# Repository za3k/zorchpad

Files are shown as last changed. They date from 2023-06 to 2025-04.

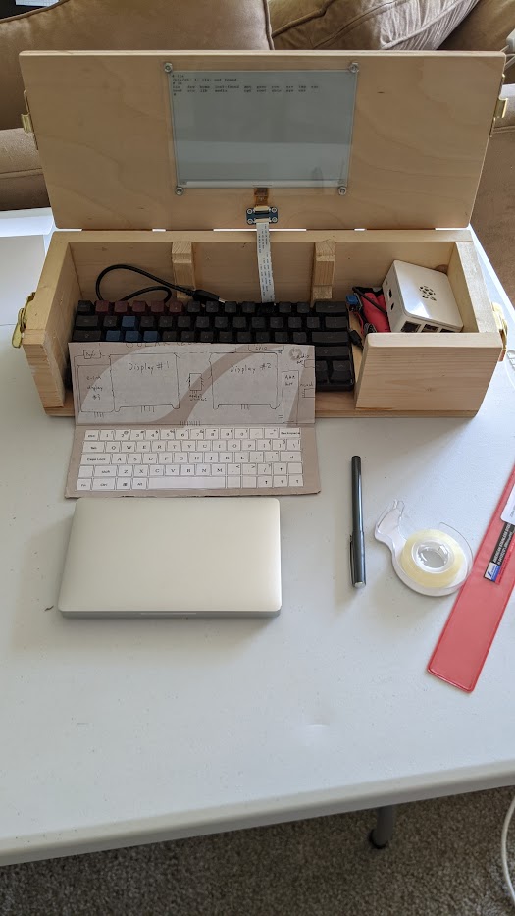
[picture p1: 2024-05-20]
photos/cardboard_zorchpad_comparison.jpg

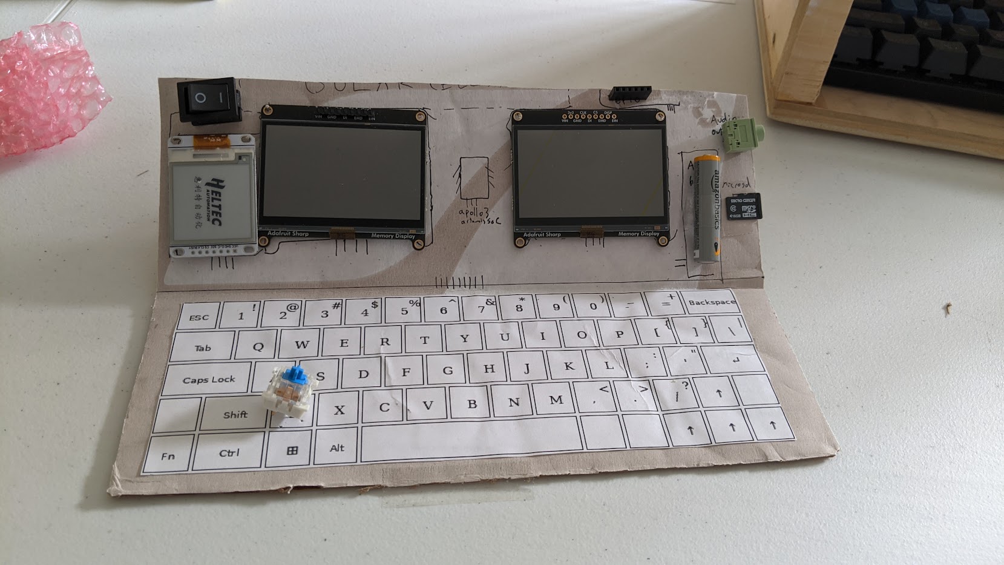
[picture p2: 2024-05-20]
photos/v0_cardboard_zorchpad.jpg

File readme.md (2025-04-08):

## (WIP) Zemu
The 'zorchpad emulator'. A basic C interface, abstracting the hardware of the zorchpad. Has a version which runs on the zorchpad and one that runs locally on PC for ease of development.

- Set/unset pixel
- Refresh screen
- Play tone
- Sleep (millis)
- Get current held key (if queue disabled)
- Get last pressed key (if queue enabled)

## Arduino Sketches

- `audio_out`: Basic beep, by rapidly toggling one pin
- `demo_screen`: A general graphics demo for the SHARP display
- `display_ram`: Output the contents of memory to the serial console and the SHARP display.
- `font`: Display text to the SHARP screen
- `keyboard_echo`: Echoes text from the keyboard to the SHARP display
- `morse_out`: Output arbitrary text to audio using morse code
- `sharp_memory_display`: Make something appear on the SHARP display

## Other
- `case_openscad`: Design of a case to hold all the parts (discontinued)
- `keyboard_layout`: Python code to generate an image of the keyboard layout.
- `yeso`/`zeso`: A low-level graphics library, used by emulator.
- `zi`: A very simple text editor based on ae.c by Anthony Howe. (unfinished)

## Parts List

From muurkha:

- one or two of the Ambiq Apollo3 devboards (probably not the
  Arduino-sized one);
- two of the 400×240 memory-in-pixel displays; and
- one or more of the Cypress S34MS01G200TFI900 gibibit Flash chips.

Purchased list:

- $21.50 Ambiq Apollo3 SoC breakout dev board. Sparkfun: [Sparkfun DEV-15444][1] (x1)
    - [Apollo3 Blue Datasheet][6] [(ambiq)][7]
        - 16 mA max current draw from I/O pins
    - [Cortex M4 Datasheet][18] [Tech Manual][19]
    - [Schematic][8]
    - [Integration Guide][9]
    - [Arduino Support][10]
    - [Visual Guide to Features][19]
    - Works with Arduino IDE
    - [Arduino Setup][18]
- $9.95 Ambiq Apollo3 SoC module. Sparkfun: [Sparkfun WRL-15484][2] (x2)
    - [Apollo3 Blue Datasheet][6] [(ambiq)][7]
    - [Cortex M4 Datasheet][18] [Tech Manual][19]
    - [Integration Guide][9]
    - [Schematic][11]
    - [Pinout][12]
- $44.95 Adafruit SHARP Memory Display Breakout - 2.7" 400x240. Adafruit: [Adafruit 4694][3] (x2)
    - [Adafruit Guide][13]
    - [Datasheet][14]
    - [Arduino Library][15]
- $6.46 4 GBit Parallel NAND (45ns). Digi-key: [S34MS04G204TFI010][4] (x2)
    - Note: 1Gbit is more like $1 but out of stock atm.
    - [Datasheet][16]
- $21.90 Low-power radio (optional). WIO-E5 MINI DEV BRD STM32WLE5JC. Digi-key, seeed studio: [Seeed 113990939][5] (x1)
    - [Datasheet][17]

Possible additional parts:
    Microsd connector (surface-mount and through-hole available)

[1]: https://www.sparkfun.com/products/15444
[2]: https://www.sparkfun.com/products/15484
[3]: https://www.adafruit.com/product/4694
[4]: https://www.digikey.com/en/products/detail/cypress-semiconductor-corp/S34MS04G204TFI010/4457680
[5]: https://www.digikey.com/en/products/detail/seeed-technology-co-ltd/113990939/13926228

[6]: https://cdn.sparkfun.com/assets/1/5/c/6/7/Apollo3-Blue-MCU-Datasheet_v0_15_0.pdf
[6]: datasheets/Apollo3-Blue-SoC_Datasheet.pdf
[7]: https://ambiq.com/wp-content/uploads/2020/10/Apollo3-Blue-SoC-Datasheet.pdf
[8]: https://cdn.sparkfun.com/assets/4/5/a/3/e/RedBoardArtemisSchematic.pdf
[8]: datasheets/Artemis-RedBoard_Schematic.pdf
[9]: https://cdn.sparkfun.com/assets/8/7/5/3/f/Artemis_Integration_Guide.pdf
[10]: https://github.com/sparkfun/Arduino_Apollo3
[11]: https://cdn.sparkfun.com/assets/5/c/b/3/c/SparkFun_Artemis.pdf
[11]: datasheets/Artemis_Schematic.pdf
[12]: https://cdn.sparkfun.com/assets/9/a/7/1/c/ArtemisModule_Pinout.pdf
[12]: datasheets/Artemis_Pinout.pdf
[18]: https://documentation-service.arm.com/static/62053f0a0ca305732a3a5c17?token=
[18]: datasheets/Arm-Cortex-M4_Datasheet.pdf
[19]: https://documentation-service.arm.com/static/5f19da2a20b7cf4bc524d99a?token=
[19]: datasheets/Arm-Cortex-M4_Manual.pdf

[13]: https://learn.adafruit.com/adafruit-sharp-memory-display-breakout
[14]: https://cdn-learn.adafruit.com/assets/assets/000/094/215/original/LS027B7DH01_Rev_Jun_2010.pdf?1597872422
[14]: datasheets/Sharp_LCD_Datasheet.pdf
[15]: https://github.com/adafruit/Adafruit_SHARP_Memory_Display

[16]: https://media.digikey.com/pdf/Data%20Sheets/Cypress%20PDFs/S34MS01G2_2G2_4G2_RevE_6-9-17.pdf
[16]: datasheets/Flash_Datasheet.pdf

[17]: https://files.seeedstudio.com/products/317990687/res/LoRa-E5%20module%20datasheet_V1.0.pdf
[17]: datasheets/Radio_Datasheet.pdf

[18]: https://learn.sparkfun.com/tutorials/artemis-development-with-arduino/all
[19]: https://learn.sparkfun.com/tutorials/hookup-guide-for-the-sparkfun-redboard-artemis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

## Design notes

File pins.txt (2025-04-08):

    37 or 50 GPIO pins?
Available (small package)
    BTLE
    33 pins (?)
    Will require either surface-mount soldering or whisker-thin wires (quite small but not theoretically un-doable)
Available (large package)
    22 pins (?)
    Can just use standard pitch headers

Requirements:
    9 pins (9 IO) - keyboard
    0 pins - power input
    7 pins (5 out, 2 IO) - SPI
        4 devices: Screen 1, Screen 2, MicroSD, E-ink
        4x chip select, 1 clock, 1 MOSI, 1 MISO
    2? pins (2 out) - Headphones
    0 pins - Microphone (integrated)
    GPIO (???? Active research)
        3 IO?)
        (shared clock with SPI)

21 pins total (7 out-only, 14 IO, 0 in)

-------------------------------------

Voltages
    Component       Operating Voltage
    ---------       -----------------
    Screen 1+2
            power   4.8-5
            I/O     2.7-3
    E-ink* 
            power   2.3-3.6 (3.3)
            I       2.3-3.6 (3.3)
            O       power minus 0.4
    Microsd**       3.3
    Artemis/Apollo3
     Redboard in    5
     Redboard out   3.3 (nominal?)
     apollo3 in     1.755-3.63
     apollo3 out    unknown
    Headphones      (Match apollo3/artemis logic output)
    GPIO            (Match shift register)
    Keyboard        (Match shift register)
    Radio           1.8-3.6
    Shift Register  ????

*this might be incorrectly for the red-white-black display, and does not consider the board it's mounted to.
    https://resource.heltec.cn/download/e-ink/154/1.54b%26w%26r/HTEW0154Z17_V11/HTEW0154Z17_V11.pdf source
**there also a is a low-voltage (1.8V) standard from 2017, but not even all new cards support it.

(ACTIVE RESEARCH)
Serial-in, parallel out
    SN74HC595B
    2-6V
Parallel-in, serial out

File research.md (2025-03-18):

Power Usage

- Power usage will be around 0.3mA @ 3V when active (0.001 W = 0.001 J/s)
- Power usage will be around 1nA @ 3V when asleep (0.000000003 W = 0.000003 J/s)

- On 2024-08-20 I tested an e-ink power supply (Waveshare 8" display) and tried updating one character at a time, watching an oscilloscope to measure power roughly. I calculated that a refresh takes 0.0375J (4ms x 250 mA x 5V) -- affordable once per 37s. I did not test cleanly how much changing different fractions of the screen affected the power.

Continuous Power Sources

- Solar
    - 20-100 lumens per watt ??
    - ~1M lux = 1W/cm^2, ~1000 lux = 1mW/cm^2 ??
    - Outdoor, daylight
        0.138 W/cm^2
    - Outdoor, night
    - Outdoor, night (IR from earth)
        Undeveloped tech
    - Indoor, electric light
        3.5-30 uW per cm^2 [source](https://blog.powerfilmsolar.com/education/the-horizon-blog/2018/8/10/outdoor-vs-indoor-solar-the-key-differences). That's 4,000x-40,000x lower than daylight. Call it 10,000x lower.
- Amorphous silicon (calculator solar cell) - 7% efficient. 0.24W per 5cm square in daylight. 0.024 mW indoors.
- Monocrystaline silicon (standard solar cell) - 15% efficient, 0.5W per 5cm square in daylight. 0.05 mW indoors.
- Keyboard typing power
- Peltier heat differential
- Tritium battery (40 W/kg, half life 12.3 years) or other betavoltaics - Maybe 1μW
- Inductive powerline charging

Batteries

- [Lithium coin cell battery life](https://www.embedded.com/how-much-energy-can-you-really-get-from-a-coin-cell/) by Jack Ganssle, 2014. Mentions internal resistance of batteries go up as they discharge.
    225 mAh = 0.225Ah = (0.225A) * (3600s) * (2-3V) = 1620-2430 J
    Shelf life? Perhaps 10 years?

    **Runtime: 18 days active, 17,000 years inactive**
- 18650 standard lithium ion (lipo) battery.

    [source](https://nathanruffing.com/wtw22/)
    ```
    1 18659 Li-ion cell = 43,074 J
    1 Calorie = 4,180 J
    1 smartphone battery charge: 41,750 J
    1 BTU = 1,060 J
    1 kBTU = 1,000,060 J
    1 watt-hour = 3,600 J
    1 kilowatt-hour = 3,600,000 J
    2,000 Calories = 8,400,000 J
    1 gallon of gas: 120,000,000 J
    ```

    18650 battery: 43,074 J 

    **Runtime: 1.3 years active, 455,000 years inactive**
- Capacitor energy
    Charge (coulombs) is capacitance (farads=coulomb/volt) times volts: Q = F V
    Energy is joules = 0.5 Q V = 0.5 F V V
        where V is voltage and F is capacitance in farads
    The biggest capacitor I have is
        1000uF, rated to 16V. This stores 0.256 J

    Runtime: 4 minutes active, 23 hours deep sleep mode

    Online, I can get a 2.7V, 1F capacitor. This stores 7.29J.
    Runtime: 20 minutes active, 15 days deep sleep mode

    Online, I can get a 25V, 1F capacitor. This stores 625J.
    Cost ≤ $0.50
    **Runtime: 7 day active, 19 year deep sleep mode**

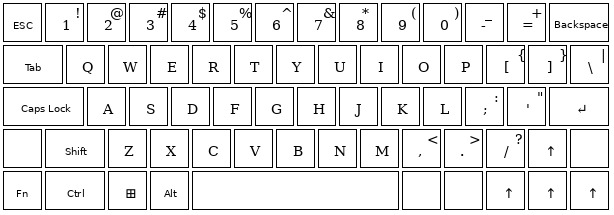
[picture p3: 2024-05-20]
photos/v0_keyboard.jpg

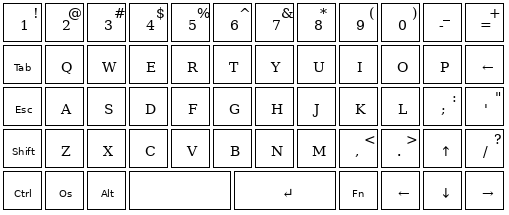
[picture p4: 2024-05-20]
photos/keyboard57.png

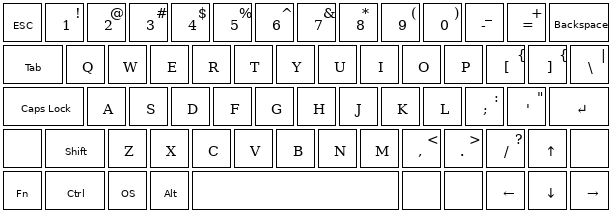
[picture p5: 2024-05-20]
photos/keyboard65.png

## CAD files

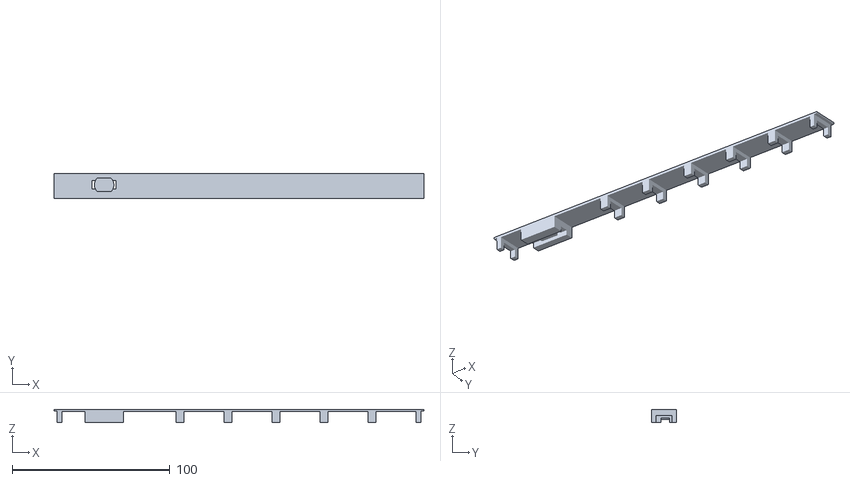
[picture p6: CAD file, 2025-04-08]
src/case_adam/Panel.stl
234.3 x 16.1 x 8.50

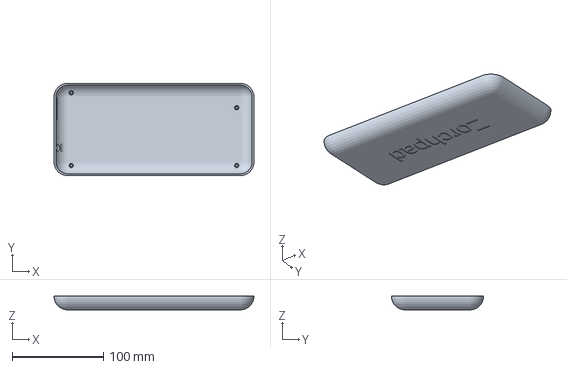
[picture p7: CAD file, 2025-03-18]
src/case_openscad/top_shell.3mf
219.7 x 101.2 x 14.9 mm

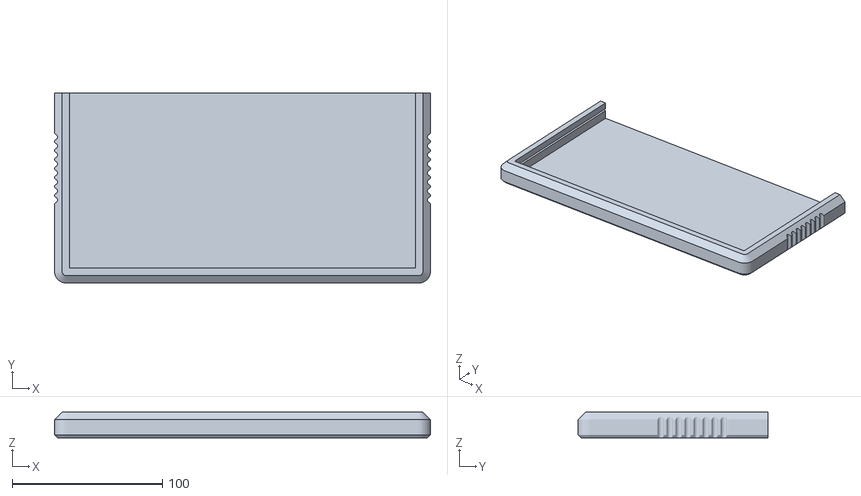
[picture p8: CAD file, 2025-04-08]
src/case_adam/Bottom Shell.stl
250.6 x 126.9 x 17.0

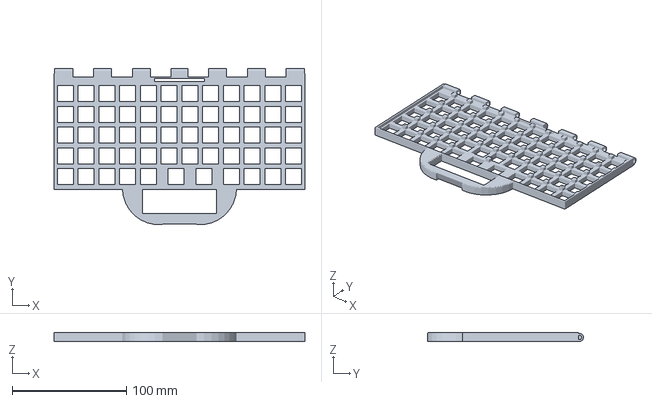
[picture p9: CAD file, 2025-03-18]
src/case_openscad/keyboard_plate.3mf
219.7 x 136.7 x 7.80 mm

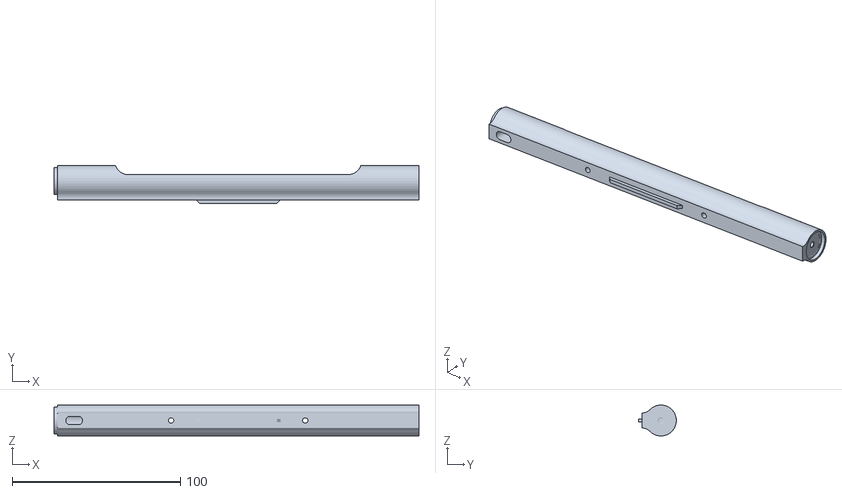
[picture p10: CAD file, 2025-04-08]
src/case_adam/Hinge.stl
216.8 x 22.4 x 18.4

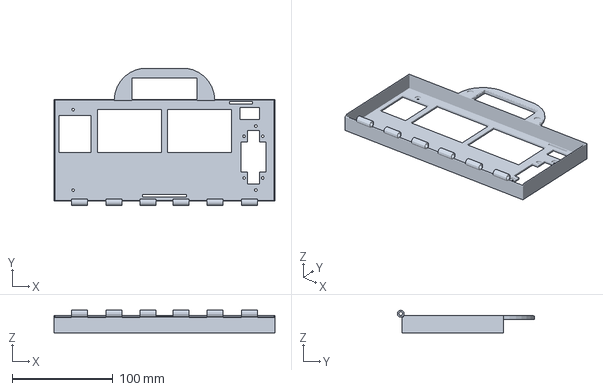
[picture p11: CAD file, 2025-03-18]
src/case_openscad/top_plate.3mf
219.7 x 136.7 x 22.5 mm

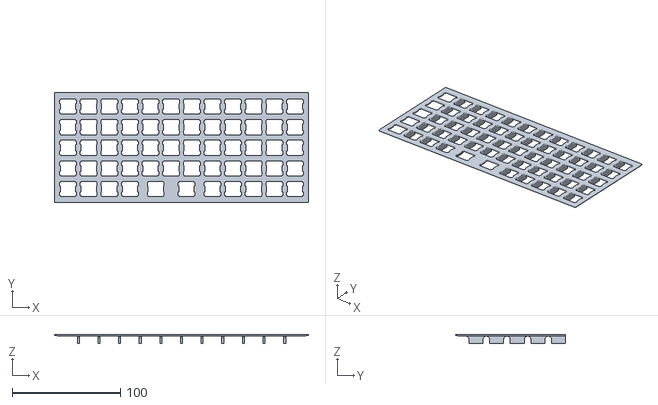
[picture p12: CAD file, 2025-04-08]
src/case_adam/Keyboard Plate v1.stl
234.6 x 101.8 x 8.25

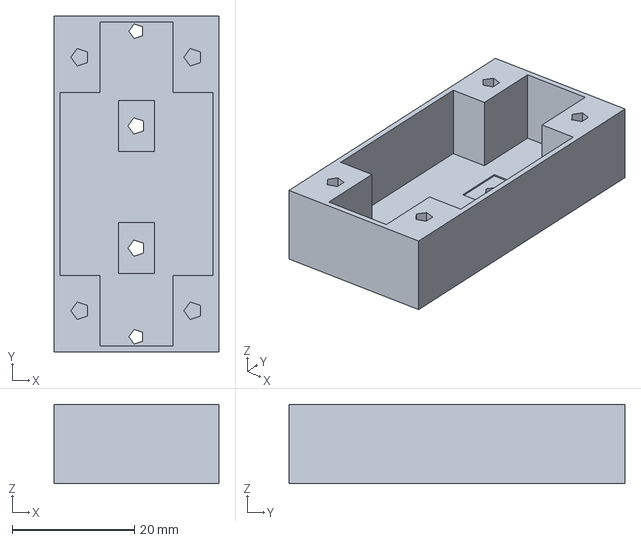
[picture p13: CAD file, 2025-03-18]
src/case_openscad/battery_box.3mf
27.0 x 55.0 x 13.0 mm

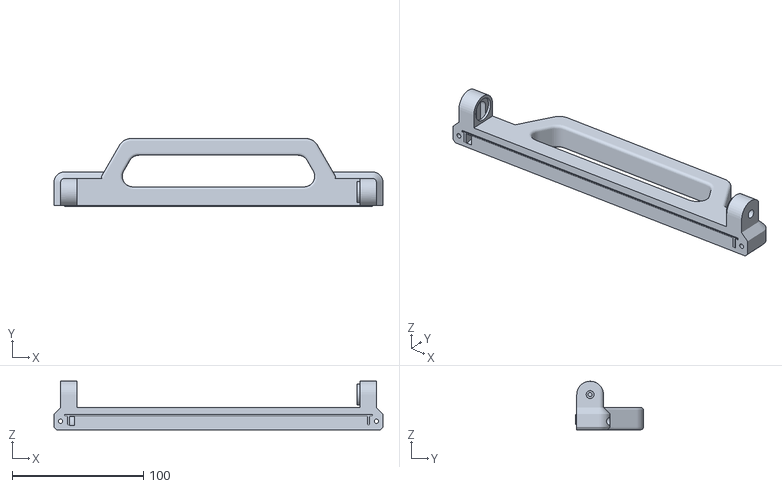
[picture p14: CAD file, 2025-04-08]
src/case_adam/Bottom Shell Rear.stl
250.6 x 51.7 x 37.0

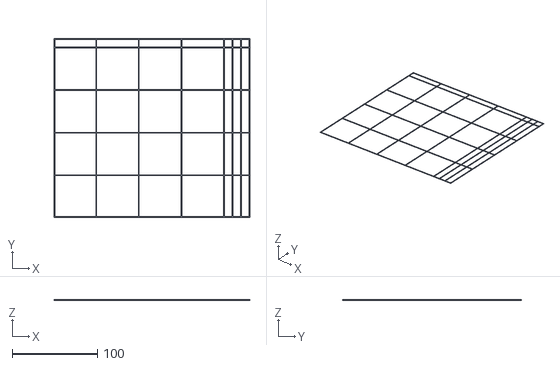
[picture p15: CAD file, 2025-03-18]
src/case_openscad/test_grid.stl
230.0 x 210.0 x 0.2

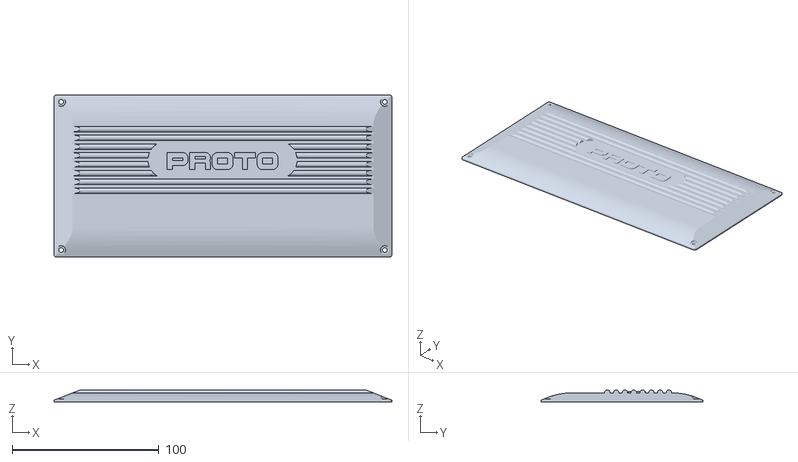
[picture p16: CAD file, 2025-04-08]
src/case_adam/Lid.stl
230.3 x 110.6 x 8.25

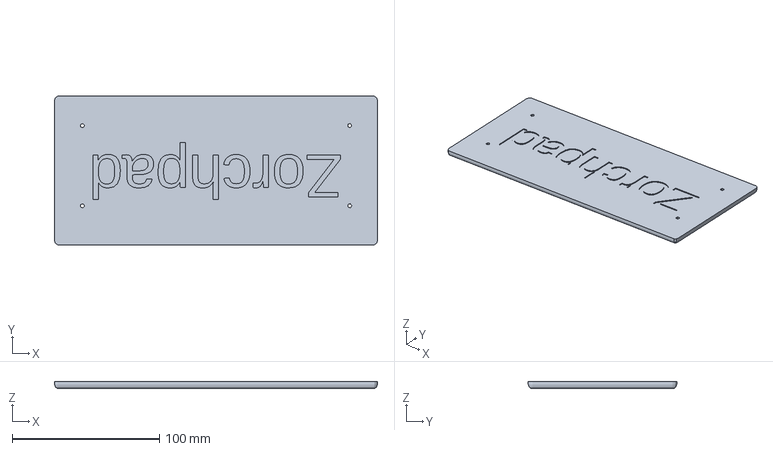
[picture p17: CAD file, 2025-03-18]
src/case_openscad/bottom_shell.3mf
219.7 x 101.1 x 4.85 mm

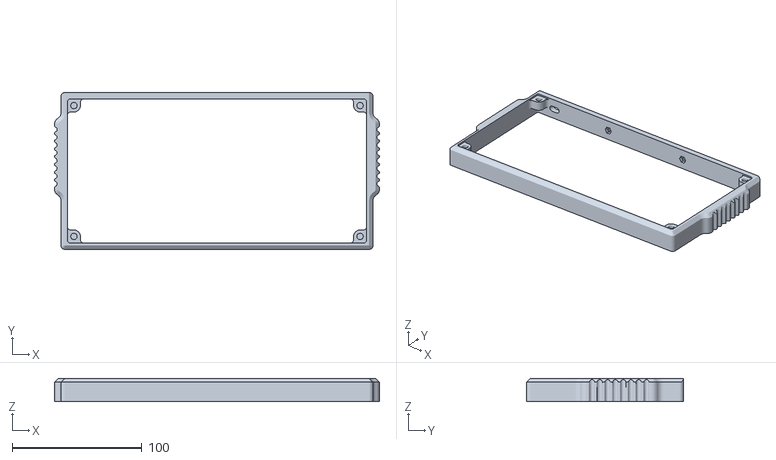
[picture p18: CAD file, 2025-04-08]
src/case_adam/Top Shell.stl
250.6 x 120.9 x 18.0

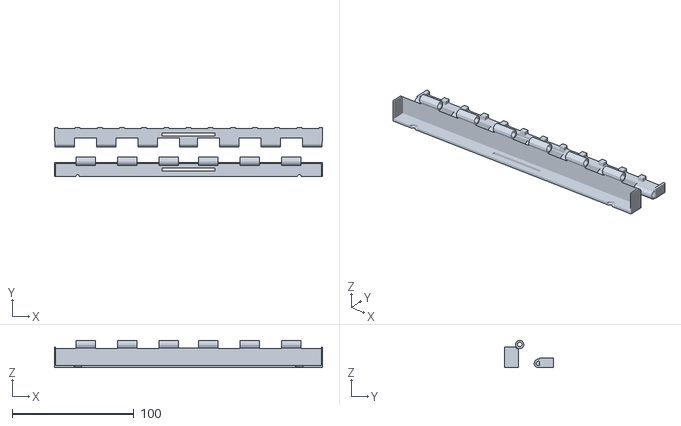
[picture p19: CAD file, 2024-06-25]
src/case_openscad/hinge.stl
219.7 x 40.0 x 22.5

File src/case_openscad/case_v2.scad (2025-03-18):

// Designed by Zachary Vance for the "Zorchpad"
//
// TO EXPORT STL FILES, run the following in a shell:
//   for part in top_shell bottom_shell keyboard_plate top_plate battery_box; do openscad -D part=\"$part\" -o $part.stl "case.scad" done
// (or if you have no idea what that means, change this variable:
part = "";
// To each of the 5 values listed above and export STL manually after each re-render.
cool_render = true;

side_thickness = 0.8;
keyboard_thickness = 4.8;

// Add a little extra room on the keyboard edges (l, r, t, b)
keyboard_edges = [side_thickness, side_thickness, 5, 2];
// There's a rim around the bottom of the keyboard to hold it up. How wide is it?
keyboard_rim = 1.5;
// How tall is the rim around the keyboard and the spacers
spacer_height = 3;

edge_left = keyboard_edges[0];
edge_right = keyboard_edges[1];
edge_top_suggestion = keyboard_edges[2]; // at y>0
edge_bottom = keyboard_edges[3];

// Keyboard grid size (h, v)
grid = [12, 5];
rows = grid[1]; cols = grid[0];
// Horizontal and vertical key spacing
//18.25 vs 18.3
key_size = [18.05, 18.05];
key_gap_size = [0.125, 0.125];
key_pitch = [key_size[0]+key_gap_size[0],key_size[1]+key_gap_size[1]];
key_spacing_h = key_pitch[0];
key_spacing_v = key_pitch[1];
// Hole size (h, v)
hole_size = [14, 14];
hole_size_h = hole_size[0];
hole_size_v = hole_size[1];

// How much do the complete keys protrude above the keyboard?
keycap_height = 15;

spacer_side_h = key_spacing_h - hole_size_h;
spacer_side_v = key_spacing_v - hole_size_v;

// M2 screw sizes
screw_diameter = 2;
screw_countersink_diameter = 3.5+2;
screw_countersink_depth = 1.5;
screw_diameter_safety = 1;
screw_insert_diameter = 4;

// add room for 17-pin header (h, v)
pins_header = [43.5, 2.5];
pins_width = pins_header[0];
pins_height = pins_header[1];
edge_top = max(edge_top_suggestion, pins_height + 6);


// Clamshell (bottom keyboard half)
clamshell_depth_b = 5;
clamshell_thickness = 2;

// Clamshell (top half)
clamshell_depth_t = 15;
plate_thickness = 2;


magnet_diameter = 6;
magnet_thickness = 1.5;

logo_depth = 0.7;

// Handle
handle_size = [100, 32];
handle_length = handle_size[0];
handle_width = handle_size[1];
handle_groove_size = [65, 22];
handle_groove_length = handle_groove_size[0];
handle_groove_width = handle_groove_size[1];
handle_rounding = 1;

// Hinge
hinge_w=0;
hinge_h=0;
hinge_d=0;
hinge_hole_dia=0;
hinge_hole_offset1=0;
hinge_hole_offset2=0;

logo_back = true;
logo_ui = true;
logo_hidden = true;

top_plate_rounded = true;

// Sides (attached to top plate)

nothing = 0.001;
big = 1000;

// x = width = col #
// y = thickness = row # 
// z = height

module rounded_linear_extrude(depth, radius, slices=50) {
    // Slice from 0...radius,             use 'offset'
    // Slice from radius..(depth-radius), just flat
    // Slice from (depth-radius)..radius, use 'offset'
    slice_thickness = depth/slices;
    union() {
        for (dz = [0:slice_thickness:depth]) {
            translate([0,0,dz])
            linear_extrude(slice_thickness+nothing)
            rounded_linear_extrude_crossection(depth, radius, dz) children();
        }
    }
}
module rounded_linear_extrude_crossection(depth, radius, dz) {
    d_end = (dz >= depth-radius) ? depth-dz-radius : (
        (dz <= radius) ? dz-radius : 0
    );
    
    // Rounded chamfer, not triangular
    inset = sqrt(radius*radius-d_end*d_end)-radius;
    
    offset(inset)
    children();
}

module flat_hole(x, y, width, height) {
    translate([x, y]) {
        square([width, height]);
    }
}

connections = [
    [1,[0]],
    [2.25, [0,24]],
    [2.75, [10,34]],
];
module key(x, y, width=1) {
    if (width <=1) key_hole(x, y, width);
    else {
        for (option = connections) {
            if (option[0] == width) {
                for (j = option[1]) {
                    translate([j,0])
                    key_hole(x, y,1);
                }
            }
        }
    }
}

module key_hole(x, y, width) {
    side_h = (key_spacing_h - hole_size_h)/2;
    side_v = (key_spacing_v - hole_size_v)/2;
    w = key_spacing_h*width - side_h*2;
    flat_hole(
        edge_left + x*key_spacing_h + side_h,
        edge_top + y*key_spacing_v + side_v,
        w, hole_size_v
    );
}

module support(x, y) {
    translate([x, y, -spacer_height/2])
    cube([spacer_side_h, spacer_side_v, spacer_height], center=true);
}

module key_support(x, y, width) {
    corner_x = edge_left + x*key_spacing_h;
    corner_y = edge_top + y*key_spacing_v;
    support(
       corner_x, corner_y
    );
}

board_w = edge_left + key_spacing_h * cols + edge_right;// + 2*key_gap_size[0];
board_h = edge_top  + key_spacing_v * rows + edge_bottom;// + 2*key_gap_size[1];

module pin_hole() {
    min_gap_to_keys = (key_spacing_v-hole_size_v);
    
    translate([board_w/2-pins_width/2, edge_top-min_gap_to_keys]) {
        square([pins_width, pins_height]);
    }
}

keys = [
    // Row, Column
    [0, 0, 1], [0, 1, 1], [0, 2, 1], [0, 3, 1], [0, 4, 1], [0, 5, 1], [0, 6, 1], [0, 7, 1], [0, 8, 1], [0, 9, 1], [0, 10, 1], [0, 11, 1],
    [1, 0, 1], [1, 1, 1], [1, 2, 1], [1, 3, 1], [1, 4, 1], [1, 5, 1], [1, 6, 1], [1, 7, 1], [1, 8, 1], [1, 9, 1], [1, 10, 1], [1, 11, 1],
    [2, 0, 1], [2, 1, 1], [2, 2, 1], [2, 3, 1], [2, 4, 1], [2, 5, 1], [2, 6, 1], [2, 7, 1], [2, 8, 1], [2, 9, 1], [2, 10, 1], [2, 11, 1],
    [3, 0, 1], [3, 1, 1], [3, 2, 1], [3, 3, 1], [3, 4, 1], [3, 5, 1], [3, 6, 1], [3, 7, 1], [3, 8, 1], [3, 9, 1], [3, 10, 1], [3, 11, 1],
    [4, 0, 1], [4, 1, 1], [4, 2, 1],
    [4, 3, 2.25], [4, 5.68, 2.25], // Spacebar, enter
    [4, 8, 1], [4, 9, 1], [4, 10, 1], [4, 11, 1],
];

module key_holes() {
  for (key = keys) key(key[1], key[0], key[2]);
}

module key_supports() {
  for (key = keys) key_support(key[1], key[0], key[2]);
}

module screw_hole(y, x, d=undef) {
    hole_d = (d == undef ? screw_diameter : d) + screw_diameter_safety;
    center_x = edge_left + x*key_spacing_h;
    center_y = edge_top + y*key_spacing_v;
    
    translate([center_x, center_y, -spacer_height/2-nothing])
    cylinder(h=spacer_height, d=hole_d, center=true);
}

module top_plate_screwholes(d) {
    top_screw_holes(d);
    
    // TODO: Move battery box holes here
}

module top_clamshell_screwholes(d) {
    translate([0, board_h,0])
    mirror([0,1,0])
    top_screw_holes(d);
}

module top_screw_holes(d) {
    screw_hole(0.1, 1, d);
    screw_hole(1, cols-1, d);
    screw_hole(rows-0.5, 1, d);
    screw_hole(rows-0.5, cols-1, d);
}

module keyboard_screwholes(d) {
    bottom_screw_holes(d);
}

module bottom_clamshell_screwholes(d) {
    bottom_screw_holes(d);
}

module bottom_screw_holes(d) {
    screw_hole(1, 1, d);
    screw_hole(1, cols-1, d);
    screw_hole(rows-1, 1, d);
    screw_hole(rows-1, cols-1, d);
}

module edge_supports() {
    // Bottom
    translate([0, board_h-keyboard_rim, -spacer_height])
    cube([board_w, keyboard_rim, spacer_height]);

    // Right
    translate([0, 0, -spacer_height])
    cube([keyboard_rim, board_h, spacer_height]);

    // Left
    translate([board_w-keyboard_rim, 0, -spacer_height])
    cube([keyboard_rim, board_h, spacer_height]);
}

module hinge_support_bottom() {
    top_rim_thickness = 4;
    top_pin_edge = 1.7;
    gap_width = pins_width;
    translate([0, board_h-top_rim_thickness-2.5, -keycap_height])
    difference() {
        cube([board_w, top_rim_thickness, keycap_height]);
            
        translate([board_w/2-gap_width/2, -nothing/2, -nothing/2])
        cube([gap_width+nothing, top_rim_thickness-top_pin_edge+nothing, keycap_height+nothing]);
    }
}

module all_key_supports() {
        difference() {
        intersection() {
            translate([0,0,-big/2]) cube([board_w, board_h, big]);
            key_supports();
        }
        
        translate([0,0,-big/2])
        linear_extrude(height=big)
        pin_hole();
        
        keyboard_screwholes();
    }
}

module keyboard_plate_main() {
    scale([1,-1,1]) {
        linear_extrude(height=keyboard_thickness)
        difference() {
            square([board_w, board_h]);
            
            union() {
                key_holes();
                pin_hole();
            }
        }
            
        // Edge supports
        edge_supports();
        
        // Grid intersection supports
        all_key_supports();
    }
}

module keyboard_plate() {
    color("lightgreen")
    translate([0,0,spacer_height])
    union() {
        difference() {
            translate([0,board_h,0])
            keyboard_plate_main();
            
            hinge_inset_bottom();
        }
        
        handle_bottom();
    }
}
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

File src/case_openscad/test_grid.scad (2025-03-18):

bed_size = [230,210];
w = 1;//0.5;
h = 0.2;

for (x = [0:10:bed_size[0]]) {
    if (x%50 == 0 || x > 200) 
    translate([max(0, x-w), 0, 0])
    rotate([-90,0,0])
    cube([w, h, bed_size[1]]);
}
for (y = [0:10:bed_size[1]]) {
    if (y%50 == 0 || y > 200) 
    translate([0, max(0, y-w), 0])
    rotate([0,90,0])
    cube([h, w, bed_size[0]]);
}

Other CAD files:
src/case_openscad/top_plate_rounded.stl
src/case_openscad/case.scad
src/case_openscad/battery_box.stl
src/case_openscad/bottom_shell.stl
src/case_openscad/keyboard_plate.stl
src/case_openscad/top_plate.stl
src/case_openscad/top_shell.stl

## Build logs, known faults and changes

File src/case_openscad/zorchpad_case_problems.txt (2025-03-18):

Hinge:
    Problem: The hinge does not freely move
    Solution: give an "empty" area around the opposite piece for each hinge area

    Problem: The hinge runs into the sides
    Solution: Remove the last bit of the flat or of the side

================

Piece 1: Keyboard
    Problem: There are a lot of supports i need to tear out.
    Solution 1:
        If at all possible, reverse the direction so it can print "upside down" from currently". This will require shifting the hinge.
    Solution 2: 
        Make the supports in the file be everywhere except where wires need to go. this reduces the amount of stuff that needs torn out
    Solution 3:
        Make the handle full thickness    

    Problem: Magnets do not fit.
    Solution: 
        Measure the hole width to make sure it fits the spec.
            If so, use 7mm holes, and make them slightly deeper.
            If not, fix that for all holes
            (Actual is 5.5mm, should be 6mm--make wider, deeper)

    Problem: Half a key is cut off
    Solution: (Troubleshoot) -- printer bed is too small

    Problem: Fingers don't easily fit in the handle
    Solution: Make the handle deeper (+ wider)

    Problem: The keyboard flexes
    Solution: Test to see if it's a problem. Screw things together.

    Problem: Screw holes too small to fit a screw

    Problem: Key fit slightly slack
	Make 0.5mm narrower?

    Perfect: Keycap spacing
    Perfect: GPIO header
    Perfect: Split spacebar pieces go on

Piece 2: Top plate
   Problem: Screen rotated 90 degrees
   Solution: Redesign

   Problem: Screw countersinks are too narrow
   Solution: Increase to 8mm across

   Problem: Battery holes screws will stick out
   Solution: Add countersinks

   Problem: Power switch does not fit in.
   Solution: Make long direction bigger by 1mm

   Problem: Sharp displays do not fit
   Solution: Make long direction bigger by 1mm

   Problem: E-ink screen a little loose
   Solution: Fine, use glue.

Piece 3: Bottom Clamshell
   Problem: a little poke-y.
   Solution: round edges more, extra vertical section

   Problem: Screw holes will not fit a screw

Piece 4: Top Clamshell
   Problem: Text is printed backwards.
   Solution: Reverse

   Problem: Screw holes will not fit a screw
   Solution: widen

Piece 5: Battery Holder
    ???

Hinge:
    Problem: There is no "stop" for the hinge.
    Solution: Add a stop

    Problem: Holes in hinge not big enough
    Solution 1: Drill them
    Solution 2: Make the hole bigger and see if that works

    Problem: Hinges don't fit together
    Solution: Reduce width by 1mm each size

General
    Problem: keyboard piece directly adjuts top piece--no room for keys when case is closed
    Solution: redesign

    Problem: Handle does not easily split
    Solution 1: Add a lip to the top piece [delay]
    Solution 2: Make the indent WAY thicker (all the way through)

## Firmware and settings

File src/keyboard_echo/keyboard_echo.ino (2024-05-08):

#include "SPI.h"
#include "tamsyn8x16r.h"

// On the keypad, the order is:
// C3 R0 R1 R2 R3 C0 C1 C2
// These pins are hooked up to those (Analog In, A0 to A3; Digital PWM out, 4 to 7)
// 16 17 18 19  7  6  5  4

int COL_PINS[4] = {6,5,4,16}; 
int ROW_PINS[4] = {17,18,19,7};

#define SPI_FREQ 1800000
#define SPI_MODE SPI_MODE1
#define SPI_ORDER MSBFIRST
#define CS_PIN 10

#define SCREEN_HEIGHT 240
#define SCREEN_WIDTH 400
#define BITS_TO_BYTES(x) ((x+7)/8)
#define SCREEN_WIDTH_BYTES BITS_TO_BYTES(SCREEN_WIDTH)
#define SCREEN_MIN 1
#define SCREEN_MAX SCREEN_HEIGHT

// We rely on GLYPH_WIDTH being 8 specifically in this code
#define GLYPH_WIDTH 8
#define GLYPH_HEIGHT 16

#define VCOM_BIT 0x40
char text[750];
char *endText;
char lastButton;

enum {
  glyph_width = 8,
  glyph_height = 16,
  font_line_bytes = (tamsyn8x16r_width + 7) / 8,
  first_font_line = 3,
};


static uint8_t vcom = 0;
inline uint8_t toggle_vcom() {
  return vcom = vcom ? 0 : VCOM_BIT;  // Toggle black polarity so the screen doesn't degrade
}

static unsigned char reverse_nibble[16] = { 0x0, 0x8, 0x4, 0xc, 0x2, 0xa, 0x6, 0xe, 0x1, 0x9, 0x5, 0xd, 0x3, 0xb, 0x7, 0xf, };
uint8_t reverse_bits(uint8_t n) {
  return (reverse_nibble[n & 0x0f] << 4) | reverse_nibble[(n & 0xf0) >> 4];
}

void clearScreen() {
  digitalWrite(CS_PIN, HIGH);
  SPI.beginTransaction(SPISettings(SPI_FREQ, SPI_ORDER, SPI_MODE));
  SPI.transfer(0x20 | toggle_vcom());
  SPI.transfer(0x00);
  SPI.endTransaction();
  delay(1);
  digitalWrite(CS_PIN, LOW);
  delay(1);
}

uint8_t framebuffer[SCREEN_HEIGHT][SCREEN_WIDTH_BYTES];
void redrawLines(int yMin, int yMax) {
  digitalWrite(CS_PIN, HIGH);
  SPI.beginTransaction(SPISettings(SPI_FREQ, SPI_ORDER, SPI_MODE));
  SPI.transfer(0x80 | toggle_vcom()); // Multi-line, 1=white and 0=black
  for (int y = yMin; y < yMax; y++) {
    uint8_t line_buffer[SCREEN_WIDTH_BYTES + 2] = {0};
    line_buffer[0] = reverse_bits(y + 1);
    memcpy(line_buffer + 1, framebuffer[y], SCREEN_WIDTH_BYTES);
    line_buffer[sizeof(line_buffer) - 1] = 0x00;
    SPI.transfer(line_buffer, sizeof(line_buffer));
  }
  SPI.transfer(0x00);
  SPI.endTransaction();
  digitalWrite(CS_PIN, LOW);
}

void drawBuffer() {
  redrawLines(0, SCREEN_HEIGHT);
}

void setPixel(int x, int y) {
  if (x < 0 || x >= SCREEN_WIDTH || y < 0 || y >= SCREEN_HEIGHT) return;
  framebuffer[y][x/8] = framebuffer[y][x/8] & ~(1 << (x%8));
}
void clearPixel(int x, int y) {
  if (x < 0 || x >= SCREEN_WIDTH || y < 0 || y >= SCREEN_HEIGHT) return;
  framebuffer[y][x/8] = framebuffer[y][x/8] | (1 << (x%8));
}

void drawLetter(char c, int y, int x) {
  int charIndex = c - 32;
  for (int r = 0; r < GLYPH_HEIGHT; r++) framebuffer[y * GLYPH_HEIGHT + r][x] = tamsyn8x16r_bits[BITS_TO_BYTES(tamsyn8x16r_width) * r + charIndex];
}
void drawLetter(char c, int pos) { // 0 < pos <= 750
  drawLetter(c, pos / 50, pos % 50);
}

void drawText(char *text) {
  int pos = 0;
  int x=0;
  int y=0;
  while (text[pos] != 0) {
    if (text[pos] == '\n') { x=0; y++; }
    else {
      drawLetter(text[pos], y, x);
      if (++x >= 50) { x=0; y++; }
    }
    pos++;
  }
}

void sendCol(int col) {
  for (int i=0; i<4; i++) {
    int pin = COL_PINS[i];
    if (col != i) pinMode(pin, INPUT_PULLUP);
    else {        pinMode(pin, OUTPUT);
                  digitalWrite(pin, LOW); }
  }
}

int readRow(int row) {
  for (int j=0; j<4; j++) {
    int pin = ROW_PINS[j];
    pinMode(pin, INPUT_PULLUP);
  }
  return digitalRead(ROW_PINS[row]) == LOW;
}

char getPressedButton() {
  int ERR = 444;
  unsigned int pressedBits=0;
  for (int i=0; i<4; i++) {
    for (int j=0; j<4; j++) {
      unsigned int currentBit = 1u << (i*4+j);
      sendCol(i);
      int b = readRow(j);
      //Serial.print(b);
      if (b) pressedBits |= currentBit;
    }
  }
  sendCol(-1);
  switch (pressedBits) {
    case 1: return '0';
    case 2: return '4';
    case 4: return '8';
    case 8: return 'C';
    case 16: return '1';
    case 32: return '5';
    case 64: return '9';
    case 128: return 'D';
    case 256: return '2';
    case 512: return '6';
    case 1024: return 'A';
    case 2048: return 'E';
    case 4096: return '3';
    case 8192: return '7';
    case 16384: return 'B';
    case 32768: return 'F';
    default: return 0;
  }
  //Serial.print("\n");
}

void setup() {
  // Chip select is always on
  pinMode(CS_PIN, OUTPUT);
  digitalWrite(CS_PIN, LOW);
  
  // Clock and data out
  SPI.begin();
  
  memset(framebuffer, 0xff, SCREEN_HEIGHT * SCREEN_WIDTH_BYTES); // Clear the buffer to white
  clearScreen();

  char *welcome =  "> ";
  strcpy(text, welcome);
  endText = text + strlen(welcome);
  lastButton = 0;

  //Serial.begin(9600);
}

void loop() {
  char pb = getPressedButton();
  if (pb && pb != lastButton) {
    if (endText - text > 700) {
      endText = text;
      text[0] = 0;
    }
    
    lastButton = pb;
    *endText++ = pb;
    *endText = 0;
  } else if (pb == 0) lastButton = 0;

  memset(framebuffer, 0xff, SCREEN_HEIGHT * SCREEN_WIDTH_BYTES);
  drawText(text);
  drawBuffer();
  delay(10);
}

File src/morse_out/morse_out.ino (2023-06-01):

/*
  Audio Output

  Output some beeps
*/

#define AUDIO_PIN 2
#define DEFAULT_FREQ 100
// Target morse spacing. I recommend against decreasing this.
#define WPM 20
// Farnsworth spacing. To learn morse, it's better to add gaps between characters instead of slowing down the whole thing. Make this as low as you need.
#define WORD_WPM 5


// the setup function runs once when you press reset or power the board
void setup() {
  // Chip select is always on
  pinMode(AUDIO_PIN, OUTPUT);
  analogWrite(AUDIO_PIN, 0);
}

void tone(int durationMs, int freq) {
  unsigned long periodMicroseconds = 1000000/freq;
  unsigned long startMicroseconds = micros();
  unsigned long us;
  do {
    us = micros();
    analogWrite(AUDIO_PIN, (us % periodMicroseconds < periodMicroseconds / 2) * 255); // Square wave 
  } while (us < startMicroseconds + durationMs*1000); 
}
void tone(int durationMs) { tone(durationMs, DEFAULT_FREQ); }

// The standard word (PARIS) is 50 units long. If a dit was 1200ms long, you would transmit at 1 wpm.
#define DIT (1200/WPM)
#define SPACE_DIT (1200/WORD_WPM)

#define dit tone(DIT); delay(DIT);
#define di dit
#define dah tone(DIT*3); delay(DIT);
// Called after dit or dah, for a total of 3 units
#define letter_space delay(SPACE_DIT*3-DIT);
// Called after dit or dah, for a total of 7 units
#define word_space delay(SPACE_DIT*7-DIT);

void sayMorse(char letter) {
  // Codes from https://morsecode.world/international/morse.html
  switch (letter) {
    case 'a': case 'A': dit dah; break;
    case 'b': case 'B': dah dit dit dit; break;
    case 'c': case 'C': dah dit dah dit; break;
    case 'd': case 'D': dah dit dit; break;
    case 'e': case 'E': dit; break;
    case 'f': case 'F': dit dit dah dit; break;
    case 'g': case 'G': dah dah dit; break;
    case 'h': case 'H': dit dit dit dit; break;
    case 'i': case 'I': dit dit; break;
    case 'j': case 'J': dit dah dah dah; break;
    case 'k': case 'K': dah dit dah; break;
    case 'l': case 'L': dit dah dit dit; break;
    case 'm': case 'M': dah dah; break;
    case 'n': case 'N': dah dit; break;
    case 'o': case 'O': dah dah dah; break;
    case 'p': case 'P': dit dah dah dit; break;
    case 'q': case 'Q': dah dah dit dah; break;
    case 'r': case 'R': dit dah dit; break;
    case 's': case 'S': dit dit dit; break;
    case 't': case 'T': dah; break;
    case 'u': case 'U': dit dit dah; break;
    case 'v': case 'V': dit dit dit dah; break;
    case 'w': case 'W': dit dah dah; break;
    case '*':
    case 'x': case 'X': dah dit dit dah; break;
    case 'y': case 'Y': dah dit dah dah; break;
    case 'z': case 'Z': dah dah dit dit; break;
    case '0': dah dah dah dah dah; break;
    case '1': dit dah dah dah dah; break;
    case '2': dit dit dah dah dah; break;
    case '3': dit dit dit dah dah; break;
    case '4': dit dit dit dit dah; break;
    case '5': dit dit dit dit dit; break;
    case '6': dah dit dit dit dit; break;
    case '7': dah dah dit dit dit; break;
    case '8': dah dah dah dit dit; break;
    case '9': dah dah dah dah dit; break;
    case ' ': word_space; return; break;
    case '&': di dah di di dit; break;
    case '\'': di dah dah dah dah dit; break;
    case '@': di dah dah di dah dit; break;
    case ')': dah di dah dah di dah; break;
    case '(': dah di dah dah dit; break;
    case ':': dah dah dah di di dit; break;
    case ',': dah dah di di dah dah; break;
    case '=': dah di di di dah; break;
    case '!': dah di dah di dah dah; break;
    case '.': di dah di dah di dah; break;
    case '-': dah di di di di dah; break;
    case '%': sayMorse("0/0"); return; break;
    case '+': di dah di dah dit; break;
    case '"': di dah di di dah dit; break;
    case '?': di di dah dah di dit; break;
    case '/': dah di di dah dit; break;
    default: return; break;
  }
  // Post-letter gap
  letter_space;
}

void sayMorse(char *words) {
  // Ignores prosigns like SOS
  while (*words != 0) {
    sayMorse(*words++);
  }
}

void loop() {
  //sayMorse("SOS "); //dit dit dit dah dah dah dit dit dit word_space;
  //sayMorse("What hath God wrought? ");
  sayMorse("Hello ");
}

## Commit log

2023-05-11 Arm manuals
2023-05-28 Fix VCOM polarity toggling, speed up from 1Hz to 15Hz with line buffers
    [sharp_memory_display.ino]
2023-06-01 Save power
2023-06-03 Let Arduino deal with src/
2023-06-03 Preliminary font work--get a framebuffer
2024-05-20 Switch to more compact notation for keyboard, close to that one thingy
2024-05-26 zorchpad case
    [case.scad]
2024-05-29 Add handle
    [case.scad, handle.scad]
2024-05-30 Added a magnet hole
    [case.scad]
2024-05-30 Add notch in the handle
    [case.scad]
2024-05-30 Add all cutouts
    [case.scad]
2024-05-30 Add simple hinge
    [case.scad]
2024-05-30 Finish hinge, add ribbon cable holes
    [case.scad]
2024-05-30 futz with keyboard key sizes
    [case.scad]
2024-05-30 Add holes to battery case
    [case.scad]
2024-05-30 Remove handle.scad
    [handle.scad]
2024-05-30 Add magnet, keys to parts list
2024-05-30 Check in rendered stl
    [case.stl]
2024-05-30 Ready for printing
    - Lay out items with correct orientation, on top of z=0
    - Separate battery case and add screw holes
    [case.scad, case.stl]
2024-05-30 Fix hinges being disconnected
    [case.scad, case.stl]
2024-05-30 Make sure all stl files are single-volume
    [battery_box.stl, bottom_shell.stl, case.scad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]
2024-05-30 Fix colors
    [case.scad]
2024-05-30 Better docs
    [case.scad]
2024-05-31 Remove case.stl
    [case.stl]
2024-06-04 Identify print problems
    [case.scad]
2024-06-04 Fix problems from first print
    [battery_box.stl, bottom_shell.stl, case.scad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]
2024-06-23 zorchpad update
    [bottom_shell.stl, case.scad, keyboard_plate.stl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]
2024-06-25 Fixed hinged overlap; reduced keyboard gap to fit inside 220mm
    [case.scad]
2024-06-25 Fix key intersection in corners
    [case.scad]
2024-06-25 Reduce to 220mm (again)
    [case.scad]
2024-06-25 New versions
    [bottom_shell.stl, case.scad, hinge.stl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]
2025-03-18 Update README mostly
    [battery_box.3mf, bottom_shell.3mf, case_v2.scad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]
2025-04-08 Adam Simonyi's case (STL only)
    [Bottom Shell Rear.stl, Bottom Shell.stl, Hinge.stl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]
2025-04-08 Keyboard pin research
2025-04-08 Start kicad schematic
    [zorchpad.kicad_pcb]
2025-04-08 Keyboard matrix schematic
    [12x5.kicad_sch, 8x8.kicad_sch, keyboard_12x5.kicad_sch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]
